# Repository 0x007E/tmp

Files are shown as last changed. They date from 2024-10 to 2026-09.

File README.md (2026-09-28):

  

# `TMP` - Temperature Warning (Temperaturwarnung)

The `TMP` is a board with an [LM358](#additional-information) or any other 2-channel operational amplifier. The board itself is driven with a voltage of `5V`. It converts the temperature (0° - 100°) from an [KTY81/210](#additional-information) to a voltage. This voltage can be coupled onboard with a Schmitt-Trigger to change the status of the connected LEDs (`green`, `red`).

Optional the converted temperature can be digitalized through an A/D converter and sent to a terminal through UART. A demo how this can be done is attached and can be tested with an [ATmega16A](#additional-information).

| Experience | Level |
|:---|:-----:|
| Soldering | ?% |
| Software | ?% |

# Downloads

| Type | File | Description |
|:---:|:---:|:---|
| Simulation | [asc](https://github.com/0x007E/tmp/raw/refs/heads/main/TMP.asc) | LTSpice Simulation | 
| Lochmaster | [lm4](https://github.com/0x007E/tmp/raw/refs/heads/main/TMP.LM4) | Stripe grid circuit board | 
| Schematic | [pdf](https://github.com/0x007E/tmp/releases/latest/download/schematic.pdf) / [cadlab](https://cadlab.io/project/28588/main/files) | Schematic files |
| Board | [pdf](https://github.com/0x007E/tmp/releases/latest/download/pcb.pdf) / [cadlab](https://cadlab.io/project/28588/main/files) | Board file |
| Drill | [pdf](https://github.com/0x007E/tmp/releases/latest/download/drill.pdf) | Drill file |
| BoM | [xlsx](https://github.com/0x007E/tmp/releases/latest/download/bom.xlsx) / [html](https://github.com/0x007E/tmp/releases/latest/download/ibom.html) | Bill of Material as Excel/interactive HTML |
| PCB | [zip](https://github.com/0x007E/tmp/releases/latest/download/kicad.zip) / [tar](https://github.com/0x007E/tmp/releases/latest/download/kicad.tar.gz) | KiCAD/Gerber/BoM/Drill files |
| Firmware | [zip](https://github.com/0x007E/tmp/releases/latest/download/firmware.zip) / [tar](https://github.com/0x007E/tmp/releases/latest/download/firmware.tar.gz) | Demo Firmware for ATmega16 |

# Hardware

The pcb is created with `KiCAD`. All files are built with `github actions` so that they are ready for a production environment.

## PCB

The circuit board is populated on one side. The best way for soldering the `SMD` components is within a vapor phase soldering system and for the `THT` components with a standard system.

### Top Layer

Top Layer

### Bottom Layer

Bottom Layer

# Configuration

To configure the `TMP` some reference voltages needs to be modified. The reference of `TP2` has to be around `~1V` and is adjusted through `RV1`. On `J2` the [KTY81/210](#additional-information) should be connected. To setup the amplification a mutimeter with temperature measurement function is needed. The voltage on `TP3` can be calculated through the following equation:

$U_{TP3}=\frac{2.5}{100}*𝜗+1$

Calculate $U_{TP3}$ with the current temperature and setup the voltage on `TP3` to the calculated value with `RV2`. The Equation is Designed for the following parameters:

| $U_{TP3}/[V]$ | Temperature $𝜗/[°C]$ |
|:---:|:---:|
| 1 | 0 |
| 3.5 | 100 |

On Jumper `J3/1` the generated voltage from the captured temperature can be measured. To connect the temperature measurement to the warning system jumper `J3` has to be shorten.

With `RV3` the limit to generate a state change of the leds can be set to a value between `2°` to `98°`. With `RV4` the hysteresis of the Schmitt-Trigger can be adjusted.

# Software

The demo firmware (`ATmega16A`) of the `TMP` can be used to digitalize the voltage with an A/D converter and transmit the data over uart to a terminal.

## Dataflow diagram

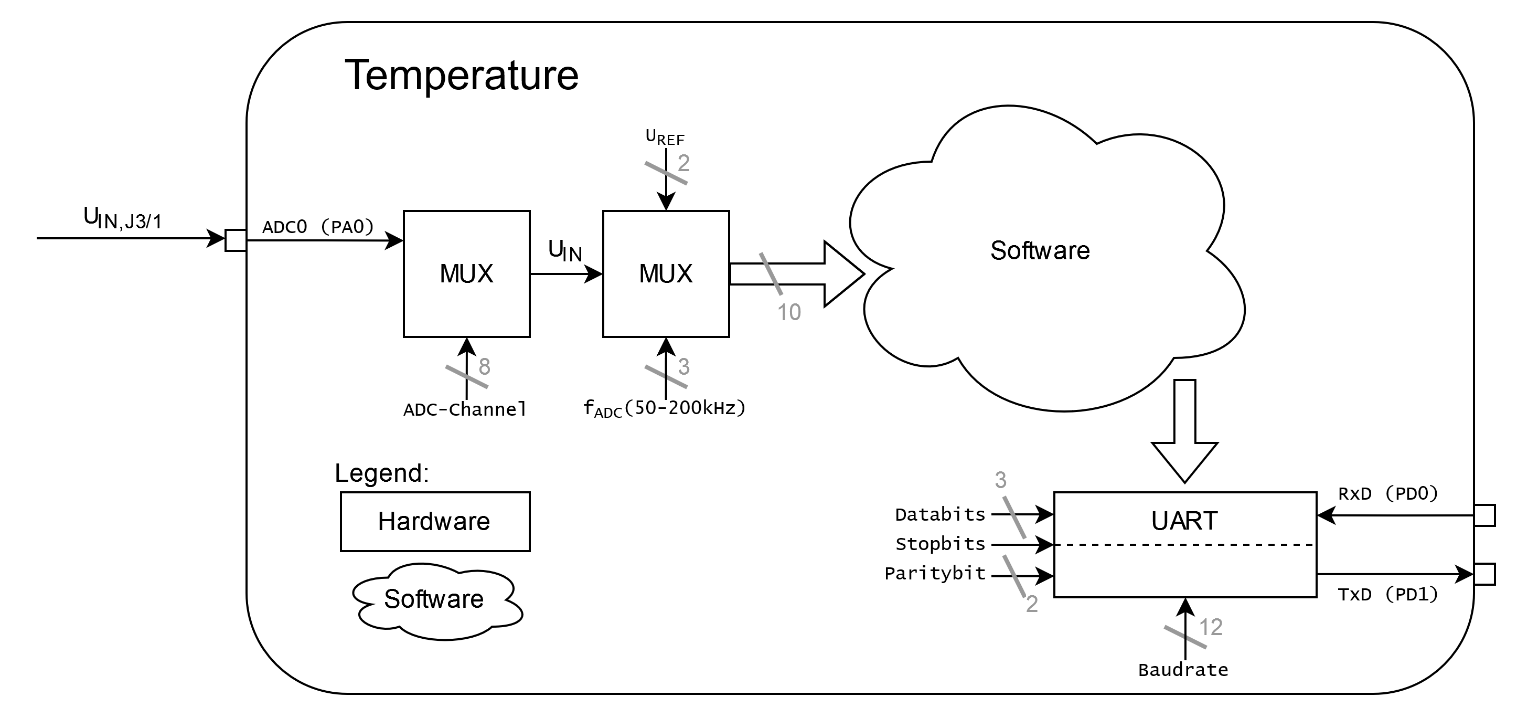
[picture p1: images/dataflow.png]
Dataflow


## Structogram

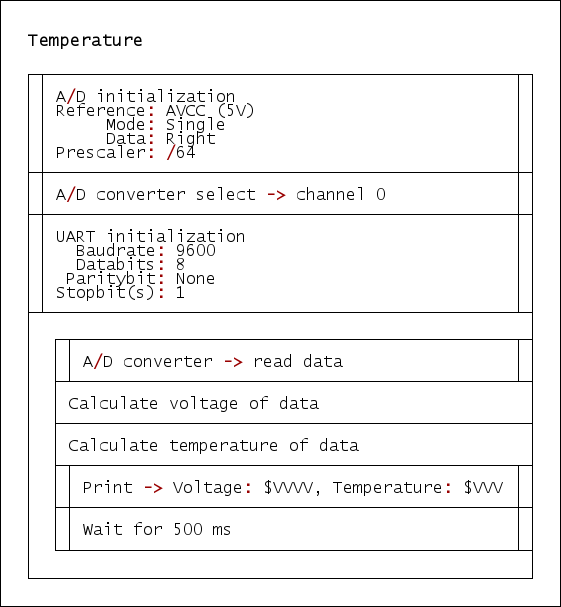
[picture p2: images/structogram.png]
Structogram


# Additional Information

| Type | Link | Description |
|:---:|:---:|:---|
| LM358 | [pdf](https://www.ti.com/lit/ds/symlink/lm358.pdf) | Dual operational amplifier |
| KTY81 | [pdf](https://www.nxp.com/docs/en/data-sheet/KTY81_SER.pdf) | Temperature sensor 2 k0hm |
| ATmega16A | [pdf](https://ww1.microchip.com/downloads/en/devicedoc/atmel-8154-8-bit-avr-atmega16a_datasheet.pdf) | Microchip ATmega16A Datasheet |

---

R. GAECHTER

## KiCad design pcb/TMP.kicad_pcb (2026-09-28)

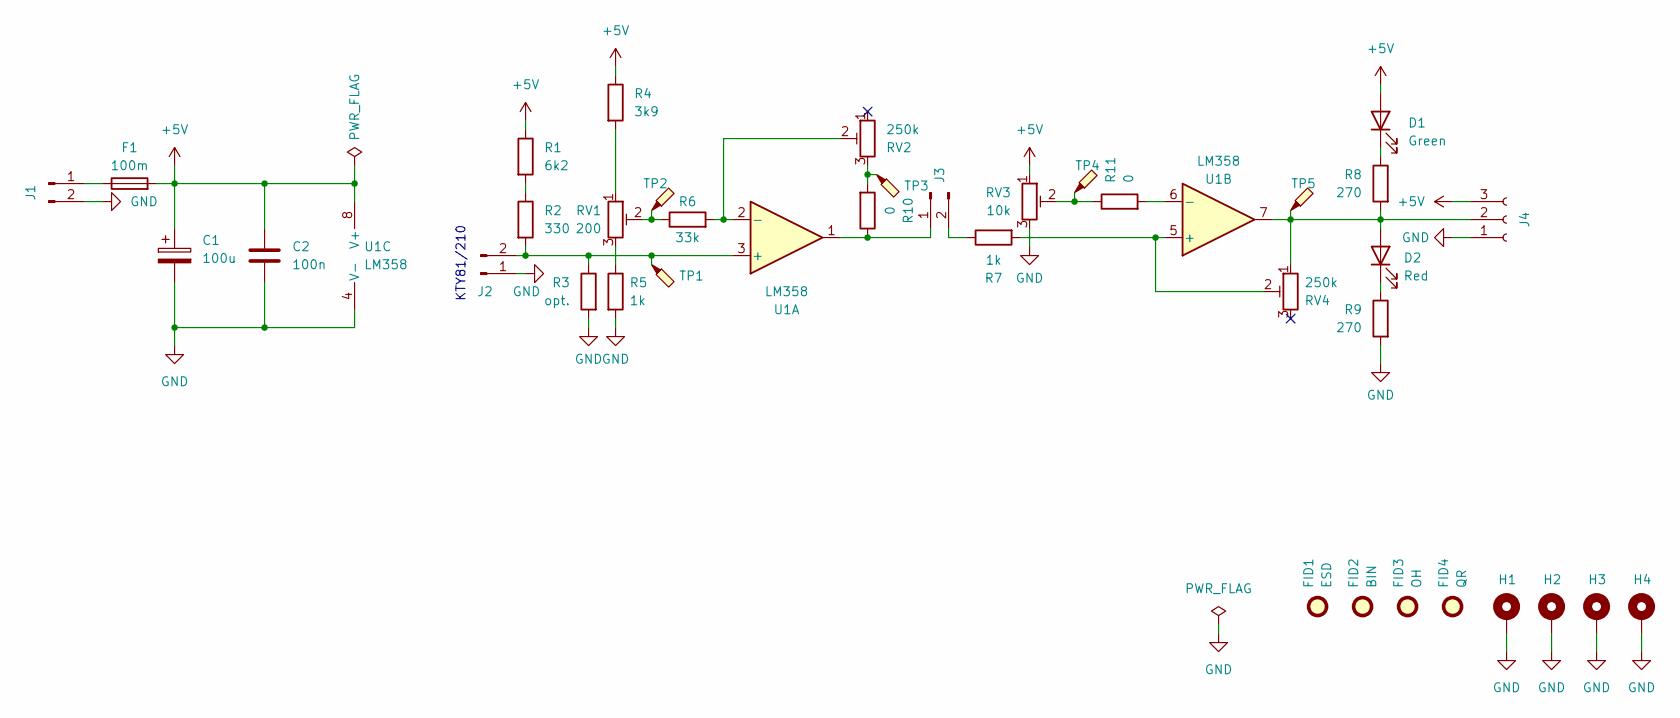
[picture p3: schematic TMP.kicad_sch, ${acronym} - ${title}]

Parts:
C1: 100u; CP_Elec_8x6.5
C2: 100n; C_1206_3216Metric
D1: Green; LED_1206_3216Metric
D2: Red; LED_1206_3216Metric
F1: 100m; Fuse_1206_3216Metric
FID1: ESD; ESD-Logo_6.6x6mm_SilkScreen
FID2: BIN; WEEE-Logo_4.2x6mm_SilkScreen
FID3: OH; OSHW-Logo_5.7x6mm_SilkScreen
FID4: QR; QR_0x007e
H1, H2, H3, H4: MountingHole_Pad; MountingHole_3.2mm_M3_DIN965_Pad
J1, J3: Conn_01x02_Pin; PinHeader_1x02_P2.54mm_Vertical
J2: Conn_01x02_Pin; WAGO_2060-402_998-404
J4: Conn_01x03_Socket; PinHeader_1x03_P2.54mm_Vertical
R1: 6k2; R_1206_3216Metric
R2: 330; R_1206_3216Metric
R3: opt.; R_1206_3216Metric
R4: 3k9; R_1206_3216Metric
R5, R7: 1k; R_1206_3216Metric
R6: 33k; R_1206_3216Metric
R8, R9: 270; R_1206_3216Metric
R10: 0; R_Axial_DIN0309_L9.0mm_D3.2mm_P12.70mm_Horizontal
R11: 0; R_1206_3216Metric
RV1: 200; Potentiometer_Bourns_3296W_Vertical
RV2, RV4: 250k; Potentiometer_Bourns_3296W_Vertical
RV3: 10k; Potentiometer_Bourns_3296W_Vertical
TP1, TP2, TP3, TP4, TP5: TestPoint_Probe; TestPoint_Pad_D1.5mm
U1: LM358; SOIC-8_3.9x4.9mm_P1.27mm

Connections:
+5V: C1.1, C2.1, D1.2 (A), F1.2, J4.3, R1.1, R4.1, RV3.1, U1.8 (V+)
GND: C1.2, C2.2, H1.1, H2.1, H3.1, H4.1, J1.2, J2.1, J4.1, R3.2, R5.2, R9.2, RV3.3, U1.4 (V-)
unnamed: D1.1 (K), R8.1
unnamed: D2.2 (A), J4.2, R8.2, RV4.1, TP5.1, U1.7
unnamed: D2.1 (K), R9.1
unnamed: F1.1, J1.1
unnamed: J2.2, R2.2, R3.1, TP1.1, U1.3 (+)
unnamed: J3.1, R10.1, U1.1
unnamed: J3.2, R7.1
unnamed: R1.2, R2.1
unnamed: R4.2, RV1.1
unnamed: R5.1, RV1.3
unnamed: R6.1, RV1.2, TP2.1
unnamed: R10.2, RV2.3, TP3.1
unnamed: R11.1, RV3.2, TP4.1
unnamed: R6.2, RV2.2, U1.2 (-)
unnamed: R7.2, RV4.2, U1.5 (+)
unnamed: R11.2, U1.6 (-)

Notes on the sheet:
KTY81/210

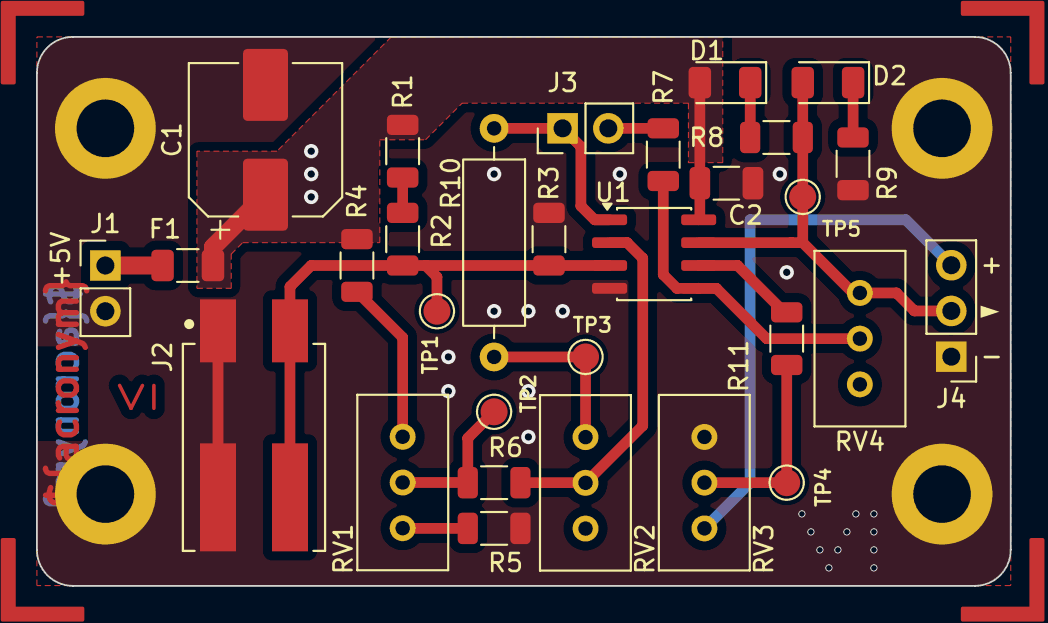
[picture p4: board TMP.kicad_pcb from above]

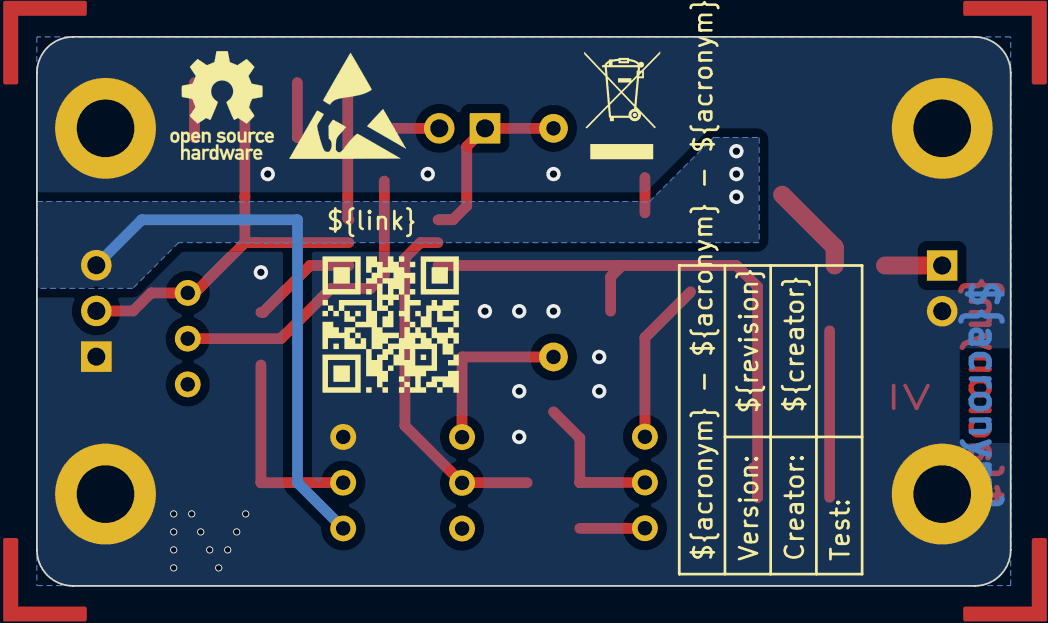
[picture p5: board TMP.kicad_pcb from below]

Board: 2 copper layers, 54.1 x 30.5 mm, 38 parts (4 on the bottom side), 18 nets.

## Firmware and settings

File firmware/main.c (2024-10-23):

#define F_CPU 12000000UL

#include <avr/io.h>
#include <util/delay.h>

#include "adc/adc.h"
#include "uart/uart.h"

int main(void)
{
    adc_init();
    adc_channel(0);
	
	uart_init();
    
    while (1) 
    {
        unsigned int adc = adc_read();
        
        unsigned int voltage = ((adc * 5000UL)>>10);  // >> 10 -> /1024
        unsigned char temp = (10 * adc - 2040UL) / 41UL;
        
		printf("Voltage: %4u, Temperature: %3u\r", voltage, temp);
		
        _delay_ms(500);
    }
}

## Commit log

2024-10-23 Fix wrong version
    [TMP.kicad_pcb]
2026-03-18 Fix vendor/vendorid at bom
    [TMP.kicad_pcb, TMP.kicad_sch]
2026-03-18 Rearrange silkscreen references
    [TMP.kicad_pcb]
2026-09-28 Update to KiCAD 9
    [TMP.kicad_pcb, TMP.kicad_sch]
2026-09-28 Rename/Add/Remove bom fields
    [TMP.kicad_pcb, TMP.kicad_sch]

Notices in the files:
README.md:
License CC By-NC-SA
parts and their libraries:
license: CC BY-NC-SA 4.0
